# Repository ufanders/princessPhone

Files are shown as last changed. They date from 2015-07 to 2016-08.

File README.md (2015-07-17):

# princessPhone

TL;DR: Bluetooth adaptor for standard wired telephones. Just plug it in.

This project bridges the gap between the wired telephones we grew up with and our modern (mobile) telephones. Contains a PIC32MX1 microcontroller, RN-52 Bluetooth audio module, Silvertel AG1170 SLIC and audio support components.

=]

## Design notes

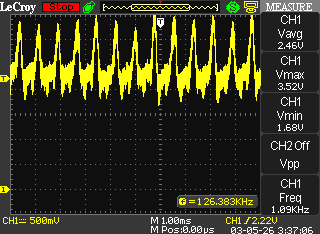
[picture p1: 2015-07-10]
doc/WA000006.BMP

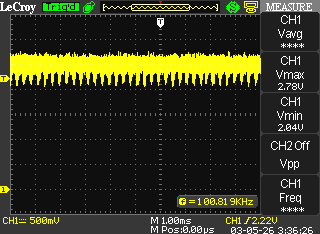
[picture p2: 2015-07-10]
doc/WA000005.BMP

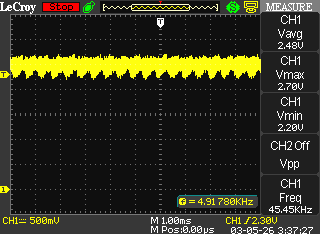
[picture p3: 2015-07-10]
doc/WA000007.BMP

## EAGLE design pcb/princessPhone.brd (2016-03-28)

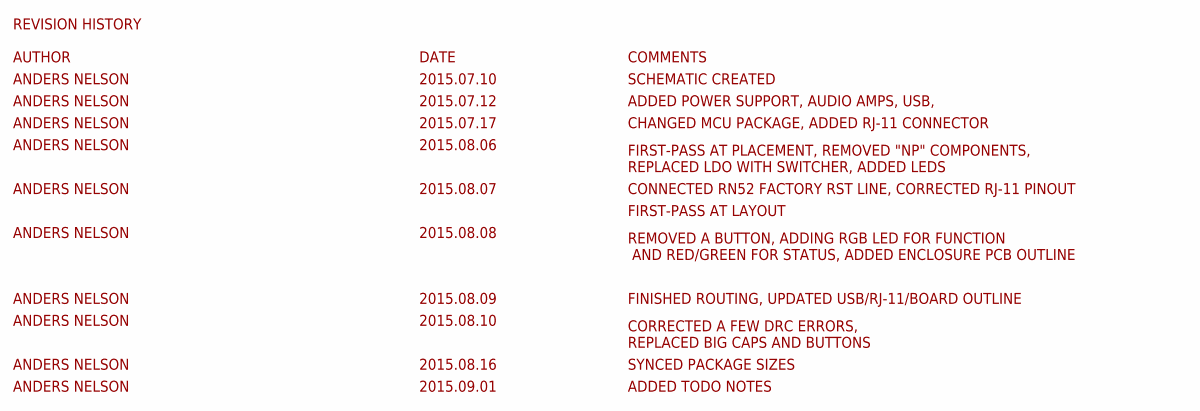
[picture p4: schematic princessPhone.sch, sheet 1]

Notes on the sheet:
REVISION HISTORY
AUTHOR
DATE
COMMENTS
ANDERS NELSON
2015.07.10
SCHEMATIC CREATED
2015.07.12
ADDED POWER SUPPORT, AUDIO AMPS, USB,
2015.07.17
CHANGED MCU PACKAGE, ADDED RJ-11 CONNECTOR
2015.08.06
FIRST-PASS AT PLACEMENT, REMOVED "NP" COMPONENTS, REPLACED LDO WITH SWITCHER, ADDED LEDS
2015.08.07
CONNECTED RN52 FACTORY RST LINE, CORRECTED RJ-11 PINOUT
FIRST-PASS AT LAYOUT
2015.08.08
REMOVED A BUTTON, ADDING RGB LED FOR FUNCTION AND RED/GREEN FOR STATUS, ADDED ENCLOSURE PCB OUTLINE
2015.08.09
FINISHED ROUTING, UPDATED USB/RJ-11/BOARD OUTLINE
2015.08.10
CORRECTED A FEW DRC ERRORS, REPLACED BIG CAPS AND BUTTONS
2015.08.16
SYNCED PACKAGE SIZES
2015.09.01
ADDED TODO NOTES

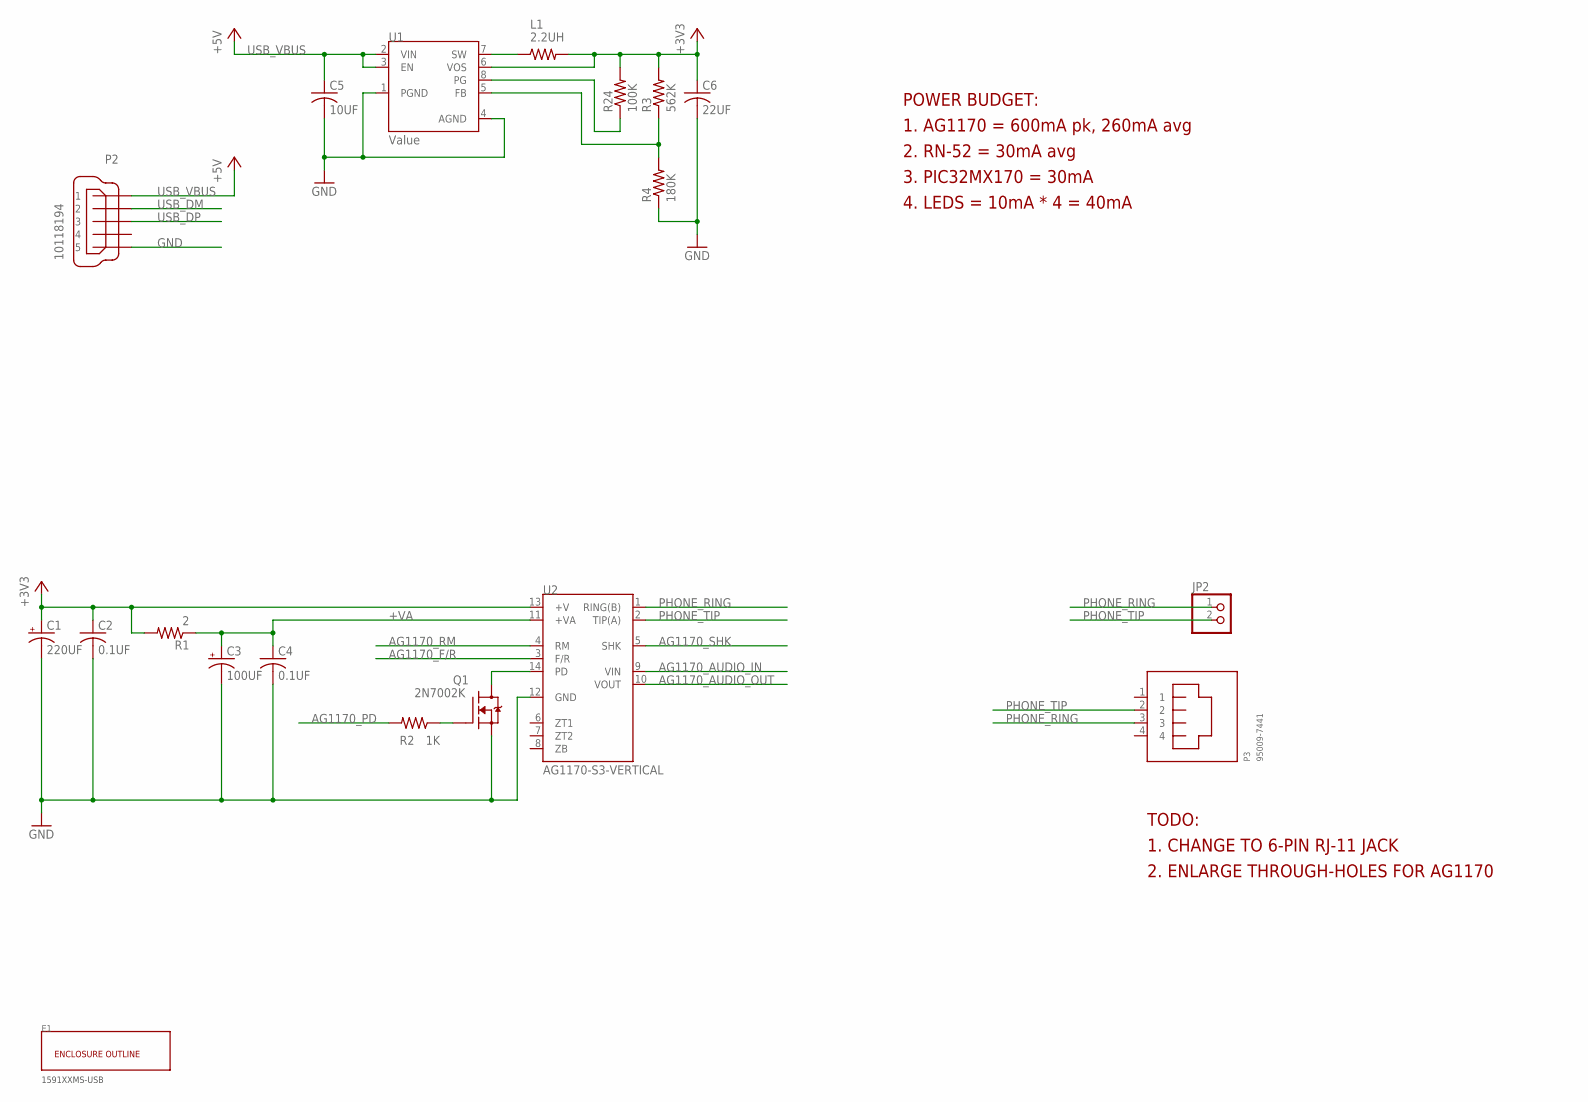
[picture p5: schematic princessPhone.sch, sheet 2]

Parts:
C1: 220UF; E2,5-7
C2, C4: 0.1UF; C0603
C3: 100UF; E2,5-7
C5: 10UF; C0603
C6: 22UF; C1206
E1: 1591XXMS-USB; 1591XXMSBK-USB
JP2: PINHD-1X2; 1X02
L1: 2.2UH; R0805
P2: 10118194
P3: 95009-7441
Q1: 2N7002K; SOT23
R1: 2; R0603
R2: 1K; R0603
R3: 562K; R0603
R4: 180K; R0603
R24: 100K; R0603
U1: Value; DGK0008A_N
U2: AG1170-S3-VERTICAL; AG1170X-S

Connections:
+3V3: C1.+, C2.1, C6.1, L1.2, R1.2, R3.2, R24.2, U1.6 (VOS), U2.13 (+V); also elsewhere on the board
+VA: C3.+, C4.1, R1.1, U2.11 (+VA)
AG1170_AUDIO_IN: U2.9 (VIN); also elsewhere on the board
AG1170_AUDIO_OUT: U2.10 (VOUT); also elsewhere on the board
AG1170_F/R: U2.3 (F/R); also elsewhere on the board
AG1170_PD: R2.2; also elsewhere on the board
AG1170_RM: U2.4 (RM); also elsewhere on the board
AG1170_SHK: U2.5 (SHK); also elsewhere on the board
GND: C1.-, C2.2, C3.-, C4.2, C5.2, C6.2, P2.5, Q1.2 (S), R4.1, U1.1 (PGND), U1.4 (AGND), U2.12 (GND); also elsewhere on the board
unnamed: Q1.1 (G), R2.1
unnamed: Q1.3 (D), U2.14 (PD)
unnamed: L1.1, U1.7 (SW)
unnamed: R24.1, U1.8 (PG)
unnamed: R3.1, R4.2, U1.5 (FB)
PHONE_RING: JP2.1, P3.3, U2.1 (RING(B))
PHONE_TIP: JP2.2, P3.2, U2.2 (TIP(A))
USB_DM: P2.2; also elsewhere on the board
USB_DP: P2.3; also elsewhere on the board
USB_VBUS: C5.1, P2.1, U1.2 (VIN), U1.3 (EN); also elsewhere on the board

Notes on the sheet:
POWER BUDGET:
1. AG1170 = 600mA pk, 260mA avg
2. RN-52 = 30mA avg
3. PIC32MX170 = 30mA
4. LEDS = 10mA * 4 = 40mA
TODO:
1. CHANGE TO 6-PIN RJ-11 JACK
2. ENLARGE THROUGH-HOLES FOR AG1170

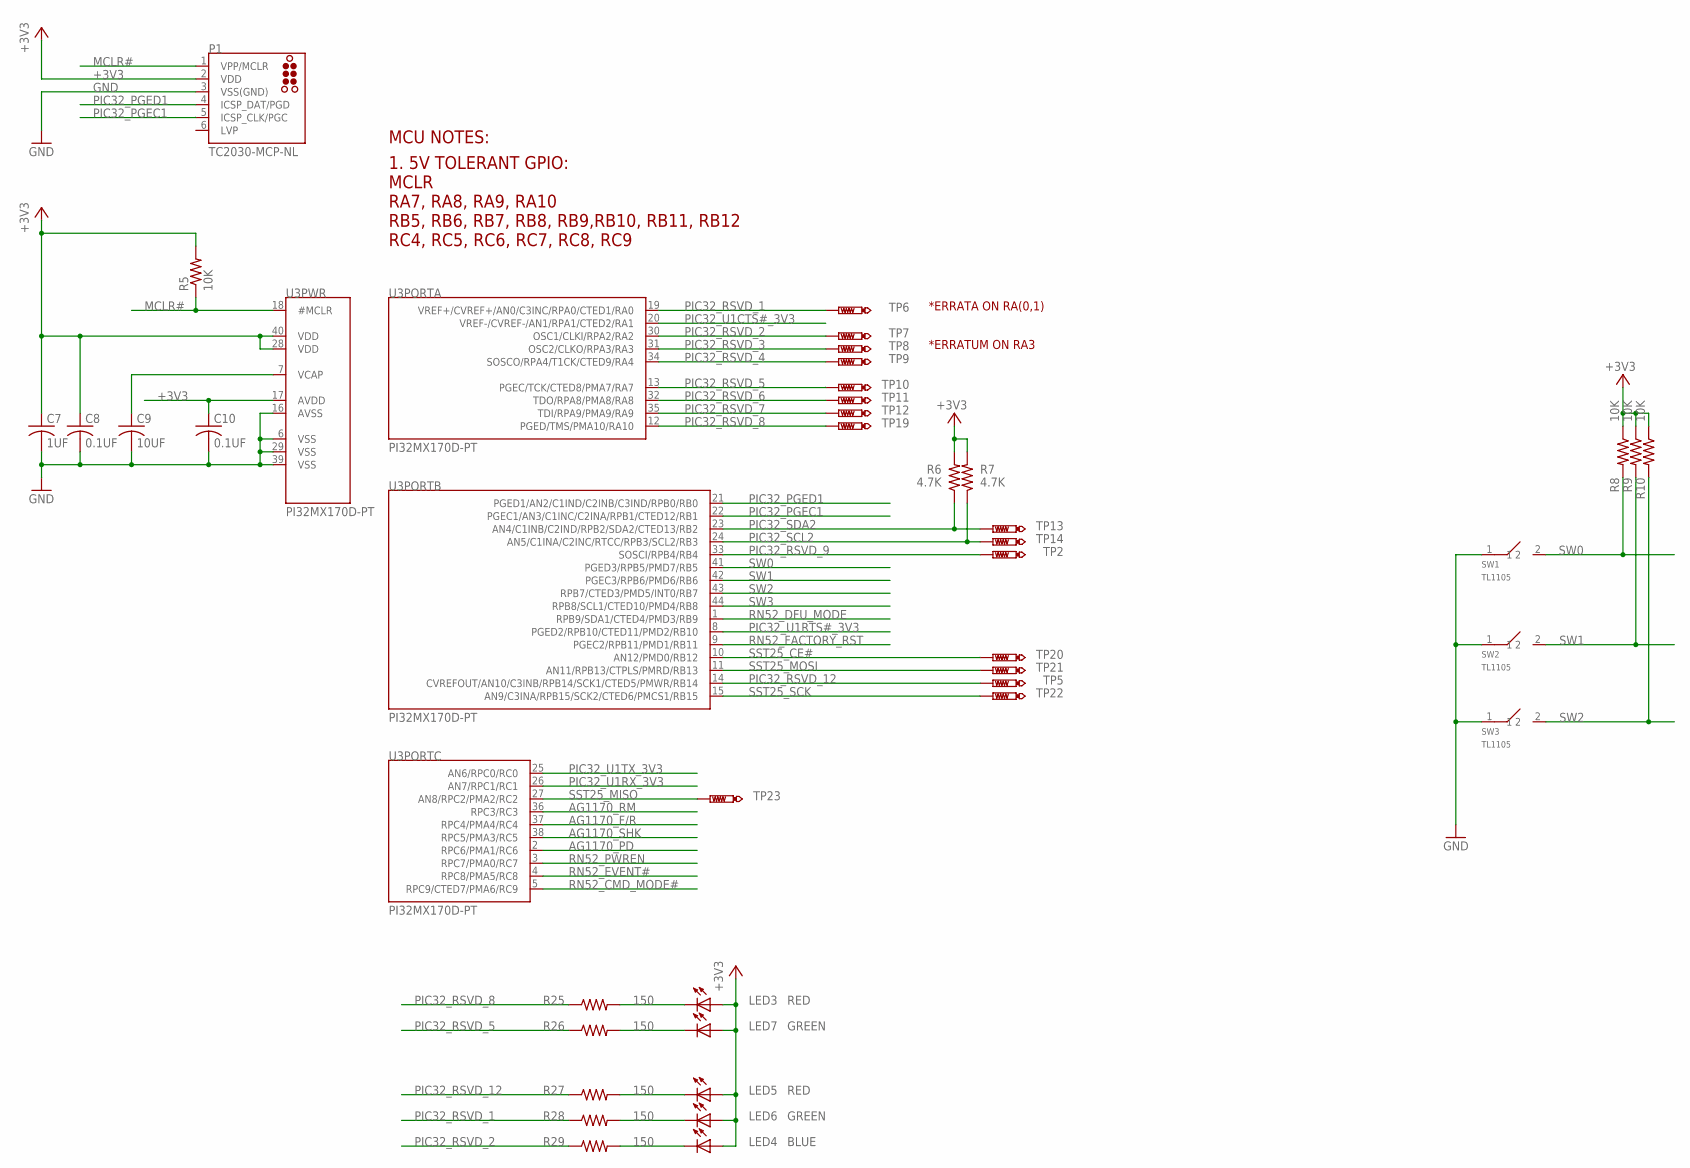
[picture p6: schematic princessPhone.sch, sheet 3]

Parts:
C7: 1UF; C0603
C8, C10: 0.1UF; C0603
C9: 10UF; C0603
LED3, LED5: RED; CHIPLED_0603
LED4: BLUE; CHIPLED_0603
LED6, LED7: GREEN; CHIPLED_0603
P1: TC2030-MCP-NL
R5, R8, R9, R10: 10K; R0603
R6, R7: 4.7K; R0603
R25, R26, R27, R28, R29: 150; R0603
SW1, SW2, SW3: TL1105; TL1105_RA
TP2, TP5, TP6, TP7, TP8, TP9, TP10, TP11, TP12, TP13, TP14, TP19, TP20, TP21, TP22, TP23: PTR1B1,27; B1,27
U3: PI32MX170D-PT; TQFP44

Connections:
+3V3: C7.1, C8.1, C10.1, LED3.A, LED4.A, LED5.A, LED6.A, LED7.A, P1.2 (VDD), R5.2, R6.2, R7.2, R8.1, R9.1, R10.1, U3.17 (AVDD), U3.28 (VDD), U3.40 (VDD); also elsewhere on the board
AG1170_F/R: U3.37 (RPC4/PMA4/RC4); also elsewhere on the board
AG1170_PD: U3.2 (RPC6/PMA1/RC6); also elsewhere on the board
AG1170_RM: U3.36 (RPC3/RC3); also elsewhere on the board
AG1170_SHK: U3.38 (RPC5/PMA3/RC5); also elsewhere on the board
GND: C7.2, C8.2, C9.2, C10.2, P1.3 (VSS(GND)), SW1.1, SW2.1, SW3.1, U3.6 (VSS), U3.16 (AVSS), U3.29 (VSS), U3.39 (VSS); also elsewhere on the board
MCLR#: P1.1 (VPP/MCLR), R5.1, U3.18 (#MCLR)
unnamed: LED5.C, R27.2
unnamed: C9.1, U3.7 (VCAP)
unnamed: LED3.C, R25.2
unnamed: LED7.C, R26.2
unnamed: LED6.C, R28.2
unnamed: LED4.C, R29.2
PIC32_PGEC1: P1.5 (ICSP_CLK/PGC), U3.22 (PGEC1/AN3/C1INC/C2INA/RPB1/CTED12/RB1)
PIC32_PGED1: P1.4 (ICSP_DAT/PGD), U3.21 (PGED1/AN2/C1IND/C2INB/C3IND/RPB0/RB0)
PIC32_RSVD_1: R28.1, TP6.TP, U3.19 (VREF+/CVREF+/AN0/C3INC/RPA0/CTED1/RA0)
PIC32_RSVD_2: R29.1, TP7.TP, U3.30 (OSC1/CLKI/RPA2/RA2)
PIC32_RSVD_3: TP8.TP, U3.31 (OSC2/CLKO/RPA3/RA3)
PIC32_RSVD_4: TP9.TP, U3.34 (SOSCO/RPA4/T1CK/CTED9/RA4)
PIC32_RSVD_5: R26.1, TP10.TP, U3.13 (PGEC/TCK/CTED8/PMA7/RA7)
PIC32_RSVD_6: TP11.TP, U3.32 (TDO/RPA8/PMA8/RA8)
PIC32_RSVD_7: TP12.TP, U3.35 (TDI/RPA9/PMA9/RA9)
PIC32_RSVD_8: R25.1, TP19.TP, U3.12 (PGED/TMS/PMA10/RA10)
PIC32_RSVD_9: TP2.TP, U3.33 (SOSCI/RPB4/RB4)
PIC32_RSVD_12: R27.1, TP5.TP, U3.14 (CVREFOUT/AN10/C3INB/RPB14/SCK1/CTED5/PM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)
PIC32_SCL2: R7.1, TP14.TP, U3.24 (AN5/C1INA/C2INC/RTCC/RPB3/SCL2/RB3)
PIC32_SDA2: R6.1, TP13.TP, U3.23 (AN4/C1INB/C2IND/RPB2/SDA2/CTED13/RB2)
PIC32_U1CTS#_3V3: U3.20 (VREF-/CVREF-/AN1/RPA1/CTED2/RA1); also elsewhere on the board
PIC32_U1RTS#_3V3: U3.8 (PGED2/RPB10/CTED11/PMD2/RB10); also elsewhere on the board
PIC32_U1RX_3V3: U3.26 (AN7/RPC1/RC1); also elsewhere on the board
PIC32_U1TX_3V3: U3.25 (AN6/RPC0/RC0); also elsewhere on the board
RN52_CMD_MODE#: U3.5 (RPC9/CTED7/PMA6/RC9); also elsewhere on the board
RN52_DFU_MODE: U3.1 (RPB9/SDA1/CTED4/PMD3/RB9); also elsewhere on the board
RN52_EVENT#: U3.4 (RPC8/PMA5/RC8); also elsewhere on the board
RN52_FACTORY_RST: U3.9 (PGEC2/RPB11/PMD1/RB11); also elsewhere on the board
RN52_PWREN: U3.3 (RPC7/PMA0/RC7); also elsewhere on the board
SST25_CE#: TP20.TP, U3.10 (AN12/PMD0/RB12)
SST25_MISO: TP23.TP, U3.27 (AN8/RPC2/PMA2/RC2)
SST25_MOSI: TP21.TP, U3.11 (AN11/RPB13/CTPLS/PMRD/RB13)
SST25_SCK: TP22.TP, U3.15 (AN9/C3INA/RPB15/SCK2/CTED6/PMCS1/RB15)
SW0: R8.2, SW1.2, U3.41 (PGED3/RPB5/PMD7/RB5)
SW1: R9.2, SW2.2, U3.42 (PGEC3/RPB6/PMD6/RB6)
SW2: R10.2, SW3.2, U3.43 (RPB7/CTED3/PMD5/INT0/RB7)
SW3: U3.44 (RPB8/SCL1/CTED10/PMD4/RB8)

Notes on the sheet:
*ERRATUM ON RA3
1. 5V TOLERANT GPIO: MCLR RA7, RA8, RA9, RA10 RB5, RB6, RB7, RB8, RB9,RB10, RB11, RB12 RC4, RC5, RC6, RC7, RC8, RC9
*ERRATA ON RA(0,1)
MCU NOTES:

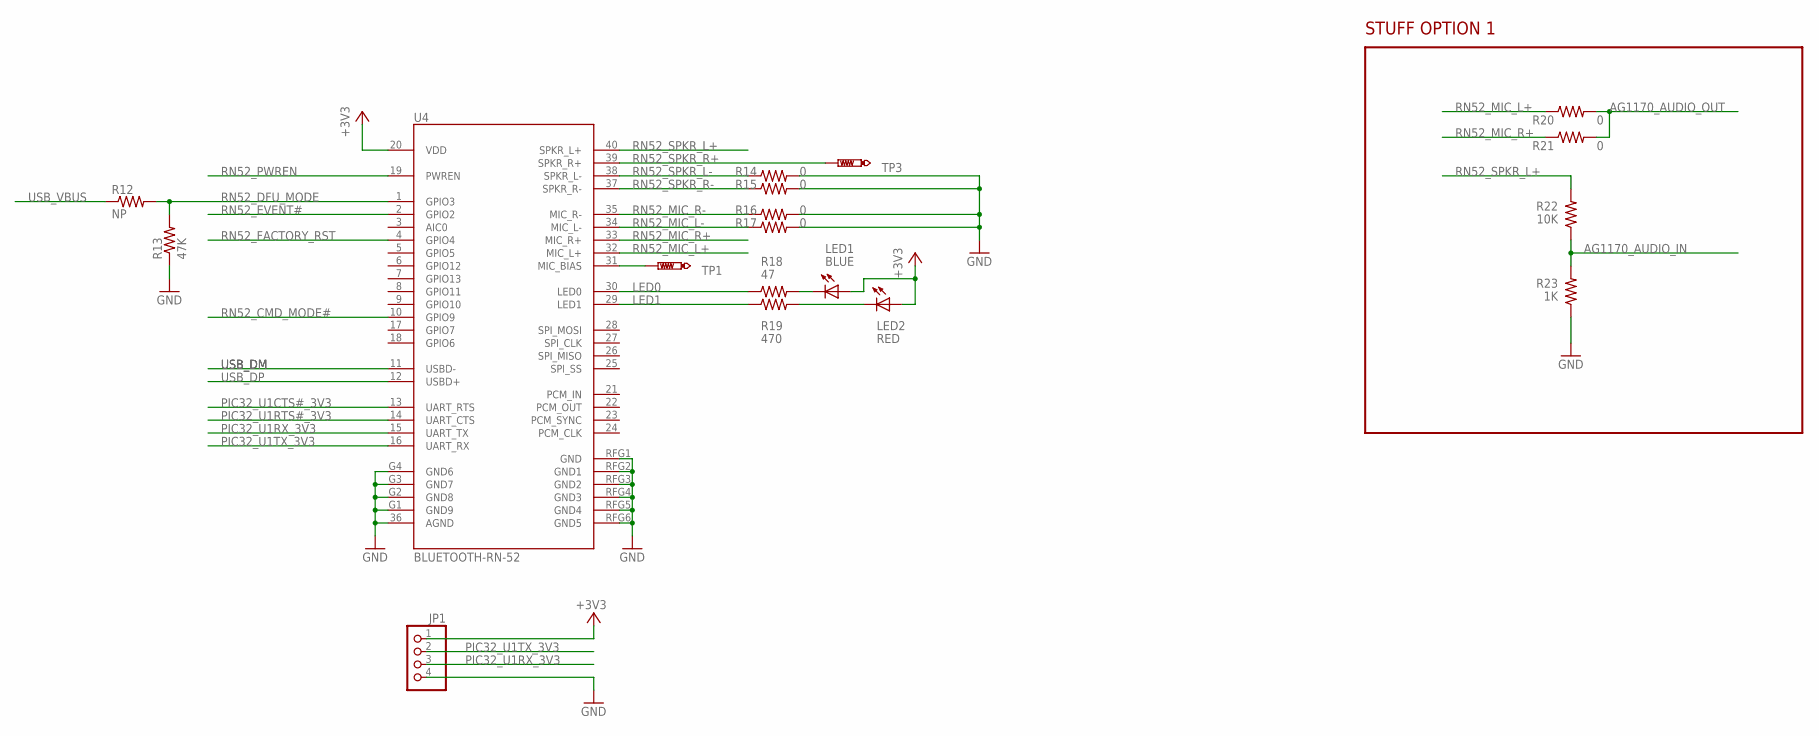
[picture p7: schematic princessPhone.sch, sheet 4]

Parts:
JP1: PINHD-1X4; 1X04
LED1: BLUE; CHIPLED_0603
LED2: RED; CHIPLED_0603
R12: NP; R0603
R13: 47K; R0603
R14, R15, R16, R17, R20, R21: 0; R0603
R18: 47; R0603
R19: 470; R0603
R22: 10K; R0603
R23: 1K; R0603
TP1, TP3: PTR1B1,27; B1,27
U4: BLUETOOTH-RN-52; RN-52

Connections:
+3V3: JP1.1, LED1.A, LED2.A, U4.20 (VDD); also elsewhere on the board
AG1170_AUDIO_IN: R22.1, R23.2; also elsewhere on the board
AG1170_AUDIO_OUT: R20.2, R21.2; also elsewhere on the board
GND: JP1.4, R13.1, R14.2, R15.2, R16.2, R17.2, R23.1, U4.36 (AGND), U4.G1 (GND9), U4.G2 (GND8), U4.G3 (GND7), U4.G4 (GND6), U4.RFG1 (GND), U4.RFG2 (GND1), U4.RFG3 (GND2), U4.RFG4 (GND3), U4.RFG5 (GND4), U4.RFG6 (GND5); also elsewhere on the board
LED0: R18.1, U4.30 (LED0)
LED1: R19.1, U4.29 (LED1)
unnamed: LED1.C, R18.2
unnamed: LED2.C, R19.2
unnamed: TP1.TP, U4.31 (MIC_BIAS)
PIC32_U1CTS#_3V3: U4.13 (UART_RTS); also elsewhere on the board
PIC32_U1RTS#_3V3: U4.14 (UART_CTS); also elsewhere on the board
PIC32_U1RX_3V3: JP1.3, U4.15 (UART_TX); also elsewhere on the board
PIC32_U1TX_3V3: JP1.2, U4.16 (UART_RX); also elsewhere on the board
RN52_CMD_MODE#: U4.10 (GPIO9); also elsewhere on the board
RN52_DFU_MODE: R12.2, R13.2, U4.1 (GPIO3); also elsewhere on the board
RN52_EVENT#: U4.2 (GPIO2); also elsewhere on the board
RN52_FACTORY_RST: U4.4 (GPIO4); also elsewhere on the board
RN52_MIC_L+: R20.1, U4.32 (MIC_L+)
RN52_MIC_L-: R17.1, U4.34 (MIC_L-)
RN52_MIC_R+: R21.1, U4.33 (MIC_R+)
RN52_MIC_R-: R16.1, U4.35 (MIC_R-)
RN52_PWREN: U4.19 (PWREN); also elsewhere on the board
RN52_SPKR_L+: R22.2, U4.40 (SPKR_L+)
RN52_SPKR_L-: R14.1, U4.38 (SPKR_L-)
RN52_SPKR_R+: TP3.TP, U4.39 (SPKR_R+)
RN52_SPKR_R-: R15.1, U4.37 (SPKR_R-)
USB_DM: U4.11 (USBD-); also elsewhere on the board
USB_DP: U4.12 (USBD+); also elsewhere on the board
USB_VBUS: R12.1; also elsewhere on the board

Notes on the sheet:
STUFF OPTION 1

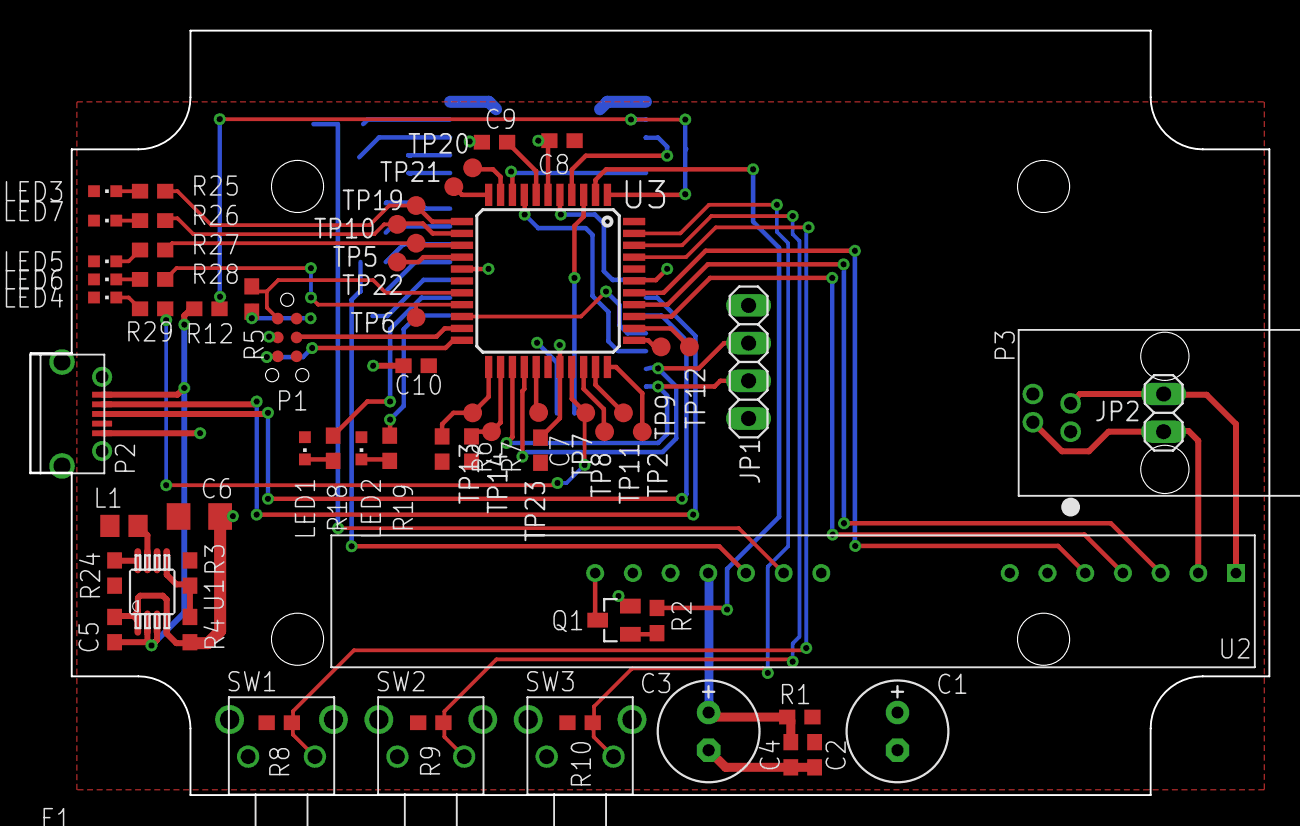
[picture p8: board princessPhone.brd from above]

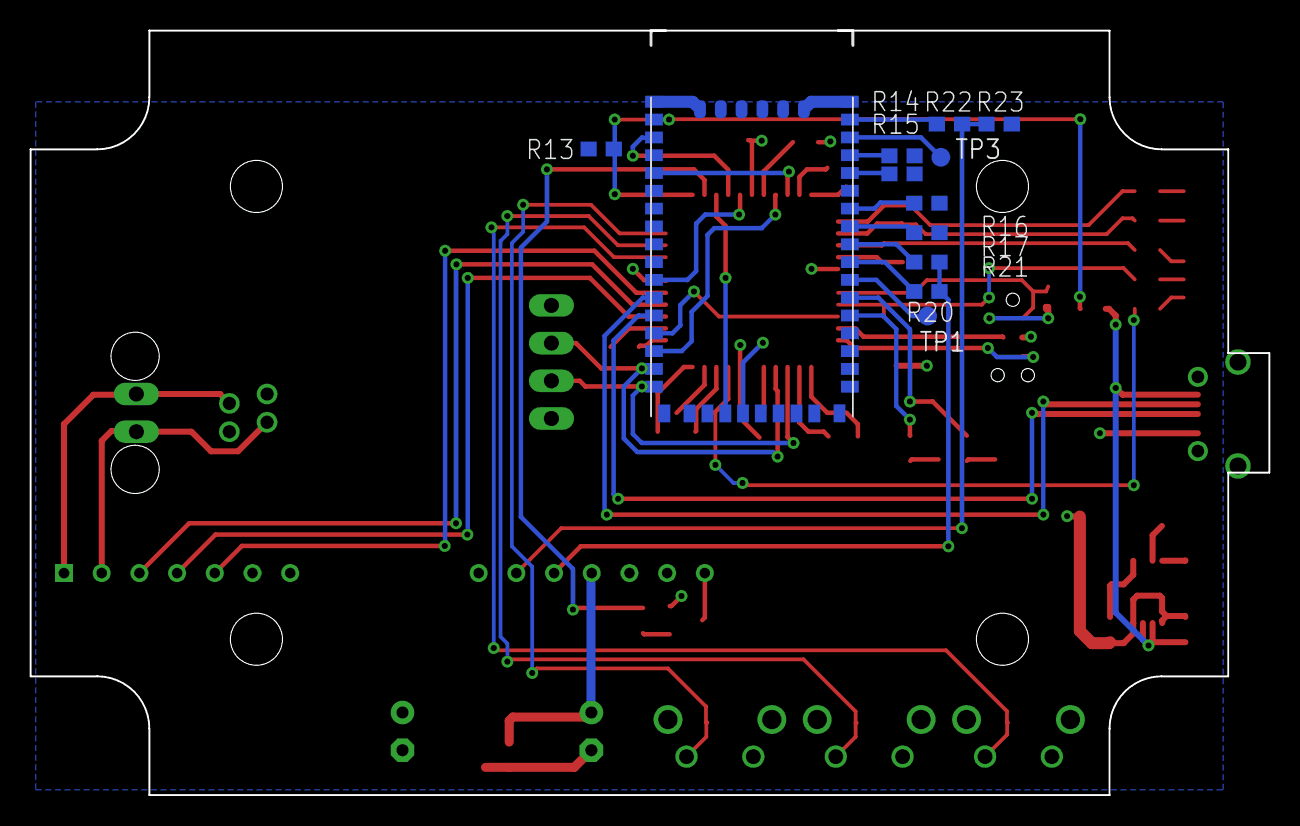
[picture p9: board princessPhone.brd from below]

Board: 2 copper layers, 83.5 x 51.5 mm, 78 parts (12 on the bottom side), 69 nets.

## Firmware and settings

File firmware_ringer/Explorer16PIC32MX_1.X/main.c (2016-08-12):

#define SET_CONFIG_FUSES

#include "HardwareProfile.h"
#include <plib.h>

unsigned char status;

int main(void)
{
    //CORE STUFF
    mJTAGPortEnable(DEBUG_JTAGPORT_OFF);    
    SYSTEMConfig(GetSystemClock(), SYS_CFG_WAIT_STATES | SYS_CFG_PCACHE);
    INTEnableSystemMultiVectoredInt();
    //INTEnableInterrupts();
    
    //BUTTON STUFF
    SW0_TRIS = 1;
    //SW1_TRIS = 1; //RB6 DOESN'T EXIST ON '270
    SW2_TRIS = 1;
    
    //LED STUFF
    LED_RED_LAT = 0;
    LED_GRN_LAT = 0;
    LED_RGB_RED_LAT = 0;
    LED_RGB_GRN_LAT = 0;
    LED_RGB_BLU_LAT = 0;
    LED_RED_TRIS = 0;
    LED_GRN_TRIS = 0;
    LED_RGB_RED_TRIS = 0;
    LED_RGB_GRN_TRIS = 0;
    LED_RGB_BLU_TRIS = 0;
    
    status = 0;
    
    status = rn52_init();
    status = dtmf_init();
    status = ag1170_init(0);
    status = rotary_init();
    
    while(status); //halt here if any init function returns an error
    
    while(1)
    {
        princessPhone_tasks();
    }
}

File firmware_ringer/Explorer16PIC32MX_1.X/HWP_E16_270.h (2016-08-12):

#ifndef HWP_E16_270_H
#define HWP_E16_270_H

#define VERSION_HARDWARE_MAJOR 'E'
#define VERSION_HARDWARE_MINOR 16

// Set configuration fuses (but only in Main.c where SET_CONFIG_FUSES is defined)
#if defined(SET_CONFIG_FUSES)

    //PROVIDES 48MHZ FCY
    #pragma config FPLLMUL  = MUL_24        // PLL Multiplier
    #pragma config FPLLIDIV = DIV_2          // PLL Input Divider
    #pragma config FPLLODIV = DIV_2     // PLL Output Divider
    #pragma config FPBDIV   = DIV_1         // Peripheral Clock divisor
    #pragma config WDTPS    = PS1           // Watchdog Timer Postscale
    #pragma config FCKSM    = CSDCMD        // Clock Switching & Fail Safe Clock Monitor
    #pragma config OSCIOFNC = OFF           // CLKO Enable
    #pragma config POSCMOD  = HS            // Primary Oscillator
    #pragma config IESO     = OFF           // Internal/External Switch-over
    #pragma config FSOSCEN  = ON           // Secondary Oscillator Enable
    #pragma config FNOSC    = PRIPLL        // Oscillator Selection

    #ifdef __DEBUG
        #pragma config CP       = OFF       // Code Protect
        #pragma config FWDTEN   = OFF       // Watchdog Timer
    #else
        #pragma config CP       = OFF        // Code Protect
        #pragma config FWDTEN   = OFF        // Watchdog Timer
    #endif

    #pragma config BWP      = OFF           // Boot Flash Write Protect
    #pragma config PWP      = OFF           // Program Flash Write Protect
    #pragma config ICESEL   = ICS_PGx2      // ICE/ICD Comm Channel Select
    #pragma config DEBUG    = ON            // Background Debugger Enable
    #pragma config FUSBIDIO = OFF
    #pragma config FVBUSONIO = OFF

#endif

// Clock frequency values
// These directly influence timed events using the Tick module.  They also are used for UART and SPI baud rate generation.
#define GetSystemClock()	(48000000ul)		// Hz
#define GetInstructionClock()	(GetSystemClock()/1)	// Normally GetSystemClock()/4 for PIC18, GetSystemClock()/2 for PIC24/dsPIC, and GetSystemClock()/1 for PIC32.  Might need changing if using Doze modes.
#define GetPeripheralClock()	(GetSystemClock()/1)	// Normally GetSystemClock()/4 for PIC18, GetSystemClock()/2 for PIC24/dsPIC, and GetSystemClock()/1 for PIC32.  Divisor may be different if using a PIC32 since it's configurable.
#define SYS_FREQ GetSystemClock()
#define PB_DIV 1

// Hardware I/O pin mappings
//UART
#define UART_RX_TRIS TRISCbits.TRISC1 //RB10 on riser card
#define UART_TX_TRIS TRISCbits.TRISC0 //RB11 on riser card
#define UART_RTS_TRIS TRISBbits.TRISB10 //RGO on riser card
#define UART_CTS_TRIS TRISAbits.TRISA1 //RE6on riser card
#define UART_RX_PPS 0b0110
#define UART_TX_PPS 0b0001
#define UART_RTS_PPS 0b0010
#define UART_CTS_PPS 0b0000

//AG1170 CONTROL LINES
#define AG1170_RM_TRIS TRISCbits.TRISC3 //RG13 on riser card
#define AG1170_FR_TRIS TRISCbits.TRISC4 //RG14 on riser card
#define AG1170_SHK_TRIS TRISCbits.TRISC5 //RG15 on riser card
#define AG1170_PD_TRIS TRISCbits.TRISC6
#define AG1170_RM_LAT LATCbits.LATC3 //RG13 on riser card
#define AG1170_FR_LAT LATCbits.LATC4 //RG14 on riser card
#define AG1170_SHK_LAT LATCbits.LATC5 //RG15 on riser card
#define AG1170_PD_LAT LATCbits.LATC6
#define AG1170_RM_PORT PORTCbits.RC3 //RG13 on riser card
#define AG1170_FR_PORT PORTCbits.RC4 //RG14 on riser card
#define AG1170_SHK_PORT PORTCbits.RC5 //RG15 on riser card
#define AG1170_PD_PORT PORTCbits.RC6

//MCU AUDIO LINES
#define PWM_TRIS TRISBbits.TRISB4
#define PWM_PPS 0b0101


//RN52 CONTROL LINES
#define RN52_DFU_MODE_TRIS TRISBbits.TRISB9
#define RN52_FACTORY_RST_TRIS TRISBbits.TRISB11
#define RN52_PWREN_TRIS TRISCbits.TRISC7
#define RN52_EVENT_L_TRIS TRISCbits.TRISC8
#define RN52_CMD_MODE_L_TRIS TRISCbits.TRISC9
#define RN52_DFU_MODE_LAT LATBbits.LATB9
#define RN52_FACTORY_RST_LAT LATBbits.LATB11
#define RN52_PWREN_LAT LATCbits.LATC7
#define RN52_EVENT_L_LAT LATCbits.LATC8
#define RN52_CMD_MODE_L_LAT LATCbits.LATC9
#define RN52_EVENT_L_PORT PORTCBits.RC8

//LEDS
#define LED_RED_TRIS TRISAbits.TRISA10
#define LED_GRN_TRIS TRISAbits.TRISA7
#define LED_RGB_RED_TRIS TRISBbits.TRISB14
#define LED_RGB_GRN_TRIS TRISAbits.TRISA0
#define LED_RGB_BLU_TRIS TRISAbits.TRISA2
#define LED_RED_LAT LATAbits.LATA10
#define LED_GRN_LAT LATAbits.LATA7
#define LED_RGB_RED_LAT LATBbits.LATB14
#define LED_RGB_GRN_LAT LATAbits.LATA0
#define LED_RGB_BLU_LAT LATAbits.LATA2

//BUTTONS
#define SW0_TRIS TRISBbits.TRISB5 //RG13 on riser card
#define SW0_PORT PORTBbits.RB5
#define SW0_PU CNPUBbits.CNPUB5
#define SW1_TRIS TRISBbits.TRISB6 //RG13 on riser card
#define SW1_PORT PORTBbits.RB6
#define SW1_PU CNPUBbits.CNPUB6
#define SW2_TRIS TRISBbits.TRISB7 //RG13 on riser card
#define SW2_PORT PORTBbits.RB7
#define SW2_PU CNPUBbits.CNPUB7
        
//SPI
#define SPI_SCK_TRIS TRISBbits.TRISB15 //RC2 on riser card
#define SPI_MOSI_TRIS TRISBbits.TRISB13 //RG14 on riser card
#define SPI_MISO_TRIS TRISCbits.TRISC2 //RG14 on riser card
#define SPI_CS_TRIS TRISBbits.TRISB12 //RE5 on riser card
#define SPI_SCK_LAT LATBbits.LATB15
#define SPI_MOSI_LAT LATBbits.LATB13
#define SPI_MISO_LAT LATCbits.LATC2 //RG14 on riser card
#define SPI_CS_LAT LATBbits.LATB12
#define SPI_SCK_PPS RPB15R
#define SPI_MOSI_PPS RPB15R
#define SPI_MISO_PPS RPB15R

//I2C
#define I2C2_SDA_TRIS TRISBbits.TRISB2 //RC2 on riser card
#define I2C2_SCL_TRIS TRISBbits.TRISB3 //RG14 on riser card

#endif	/* HWP_E16_270_H */

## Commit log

2015-07-10 Created schematic. -Added SLIC to library. -Added scope grabs to doc.
    [princessPhone.sch]
2015-07-13 Added power, audio, usb.
    [princessPhone.brd, princessPhone.sch]
2015-07-17 -Changed MCU package -Added RJ-11 connector
    [princessPhone.brd, princessPhone.sch]
2015-07-25 -Added to library -Added line-level components -Cleaned up schematic
    [princessPhone.brd, princessPhone.sch]
2015-08-07 Replaced leo with switcher, finished first-pass layout, added LEDs.
    [princessPhone.brd, princessPhone.sch]
2015-08-08 FIRST PASS AT LAYOUT
    [princessPhone.brd, princessPhone.sch]
2015-08-09 REMOVED BTN, ADDING LEDS, ADDED OUTLINE
    [princessPhone.brd, princessPhone.sch]
2015-08-09 FINISHED ROUTING
    [princessPhone.brd, princessPhone.sch]
2015-08-10 UPDATED USB/RJ-11/OUTLINE
    [princessPhone.brd, princessPhone.sch]
2015-08-11 Replaced placeholder components with proper ones.
    [princessPhone.brd, princessPhone.sch]
2015-08-17 Synced package sizes.
    [princessPhone.brd, princessPhone.sch]
2015-09-01 Program runs, UART works but init clobbers timer system.
2016-03-28 Post-fab PCB tweaks.
    [princessPhone.brd, princessPhone.sch]
2016-08-12 Continued filling in functions. -Serial port still doesn't work.
    [HWP_E16_270.h, dtmf.c, main.c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]

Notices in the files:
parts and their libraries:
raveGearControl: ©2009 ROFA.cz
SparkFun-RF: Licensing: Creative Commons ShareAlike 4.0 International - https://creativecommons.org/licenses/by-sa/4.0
